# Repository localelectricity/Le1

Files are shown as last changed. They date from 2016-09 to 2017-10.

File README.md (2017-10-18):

# L.E.One
A universal input USB power supply which makes it easy to charge your cell phone or light your home, using any type of electrical energy source. 

The power supply is able to accept DC as well as AC electricity, which is then converted into a smooth, uniform 5V for USB powered devices.

The power supply also provides feedback on how your generation device is performing through a simple UI.

# System Overview

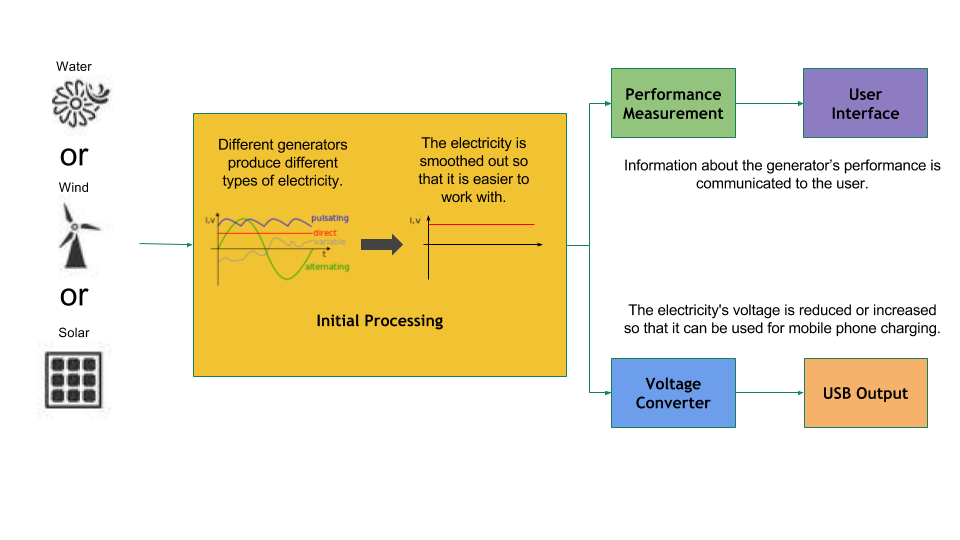
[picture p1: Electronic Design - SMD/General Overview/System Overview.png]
System Overview


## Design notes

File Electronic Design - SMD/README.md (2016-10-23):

# Electronic Design
All electronic design files are kept here.

Contents description:

- [Eagle Files & BOMs](Eagle%20Files%20&%20BOMs): Contains all the files required to view our designs in CadSoft Eagle as well as bills of materials.

- [Gerbers](Gerbers): Contains all the files required by PCB manufacturers.

- [General Overview](General%20Overview): Contains the overview image files.

- [PDFs](PDFs): Contains PDF versions of schematics and PCB layouts of our designs.

# Block Diagramme

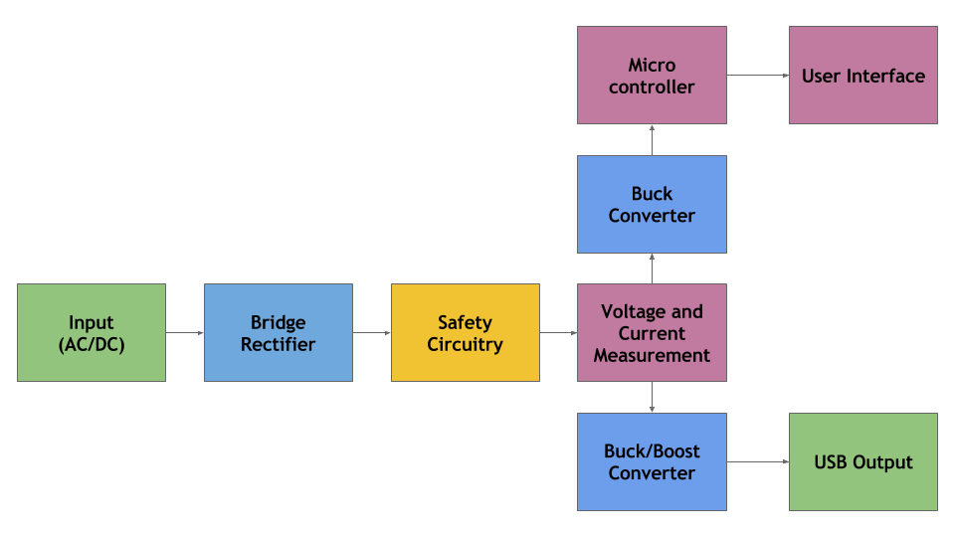
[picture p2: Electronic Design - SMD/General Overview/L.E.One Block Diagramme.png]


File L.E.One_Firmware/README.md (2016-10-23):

# MVP Firmware
All firmware for the L.E.One is kept here.

Firmware is written using arduino.

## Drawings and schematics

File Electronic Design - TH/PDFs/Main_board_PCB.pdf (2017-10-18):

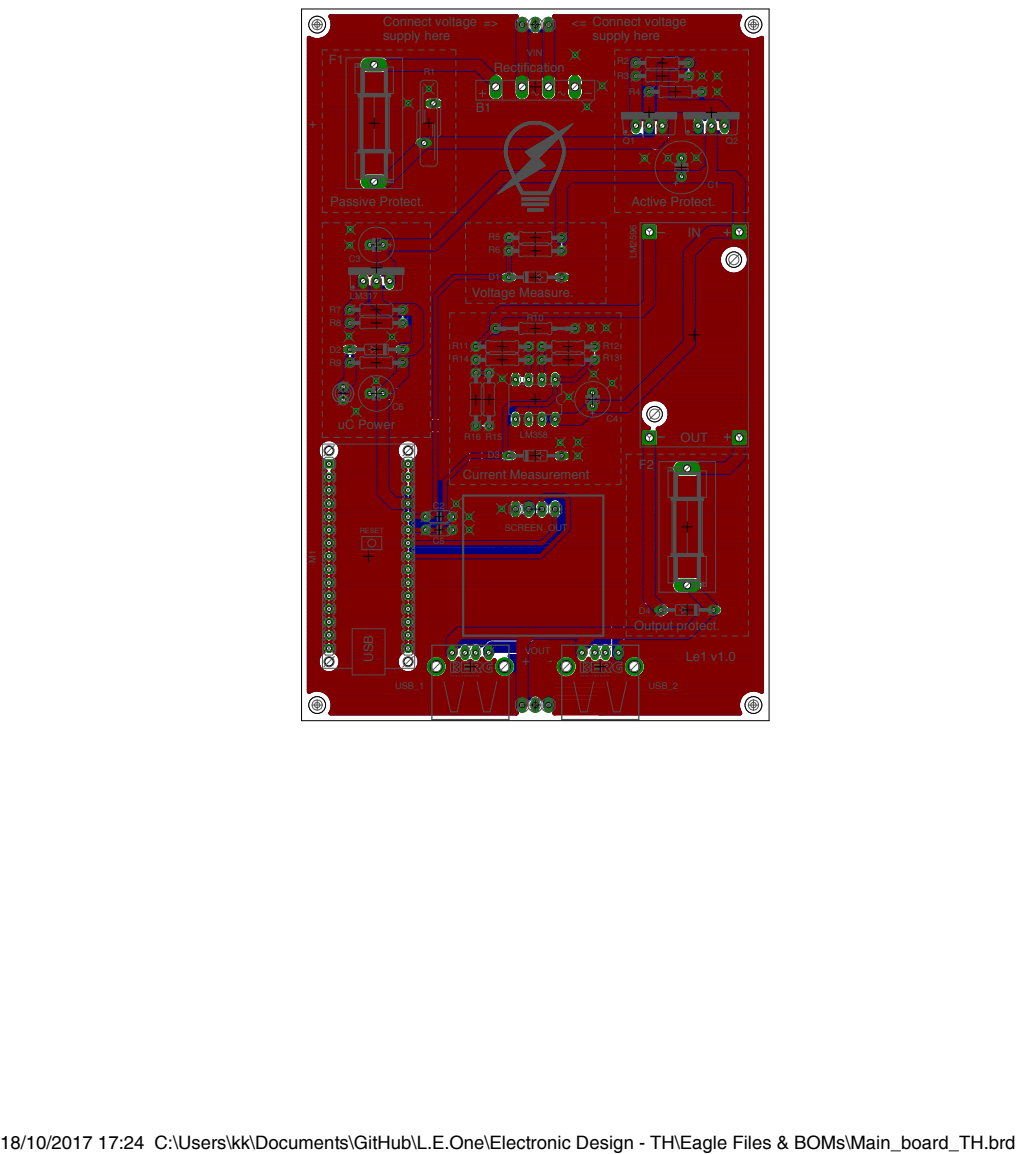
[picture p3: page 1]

+ Connect voltage | | R2

VIN

LM317 | Voltage Measure.

uC Power | C4

18/10/2017 17:24 C:\Users\kk\Documents\GitHub\L.E.One\Electronic Design - TH\Eagle Files & BOMs\Main_board_TH.brd

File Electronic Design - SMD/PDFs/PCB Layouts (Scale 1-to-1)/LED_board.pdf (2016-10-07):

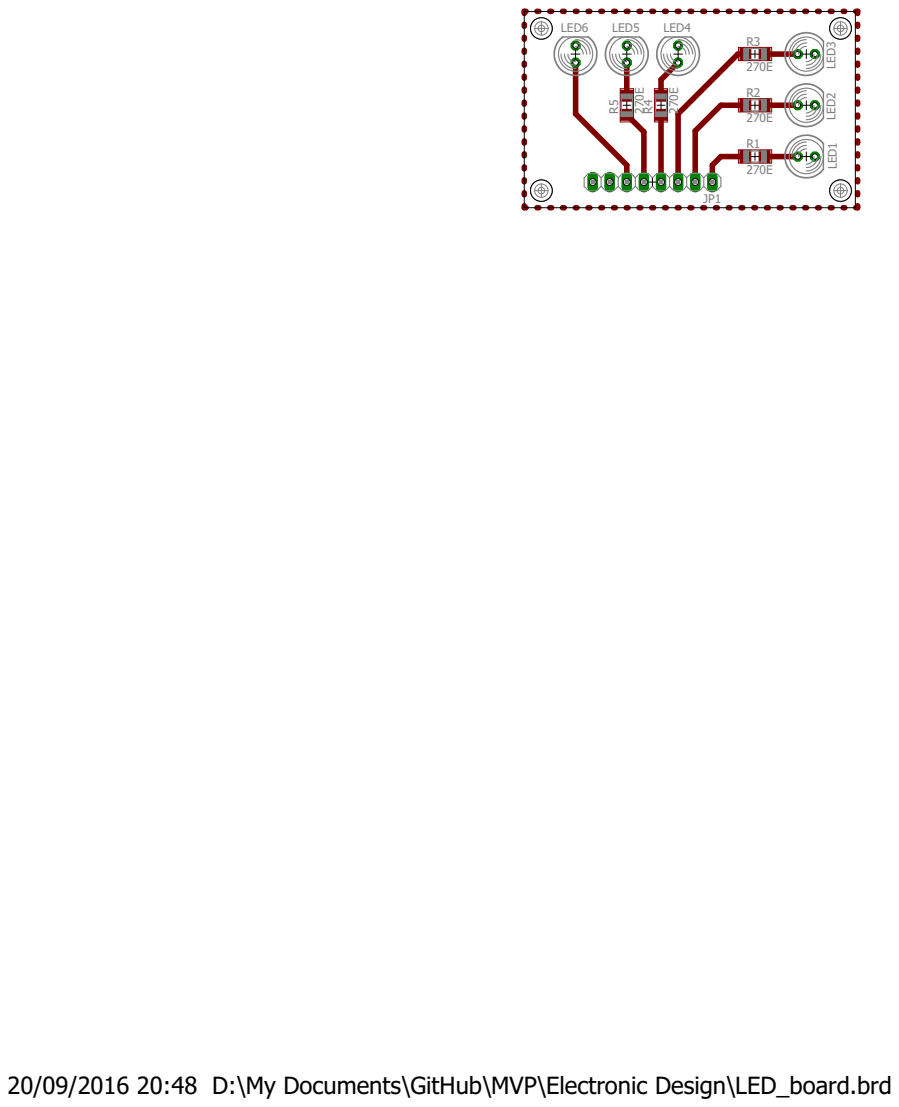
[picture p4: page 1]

20/09/2016 20:48 D:\My Documents\GitHub\MVP\Electronic Design\LED_board.brd

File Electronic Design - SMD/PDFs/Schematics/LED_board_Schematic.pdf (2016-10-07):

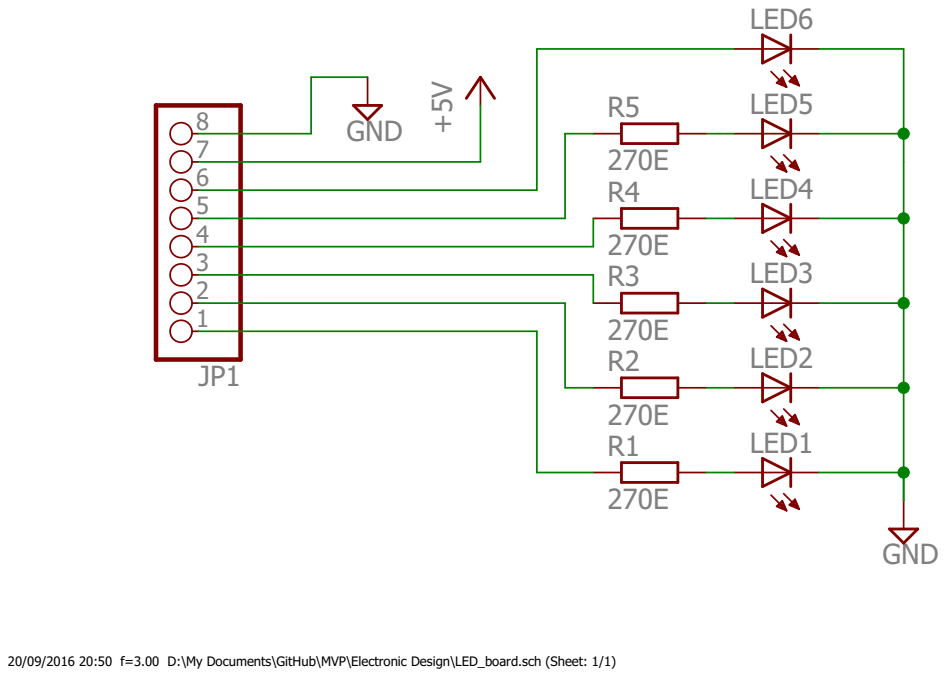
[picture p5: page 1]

20/09/2016 20:50 f=3.00 D:\My Documents\GitHub\MVP\Electronic Design\LED_board.sch (Sheet: 1/1)

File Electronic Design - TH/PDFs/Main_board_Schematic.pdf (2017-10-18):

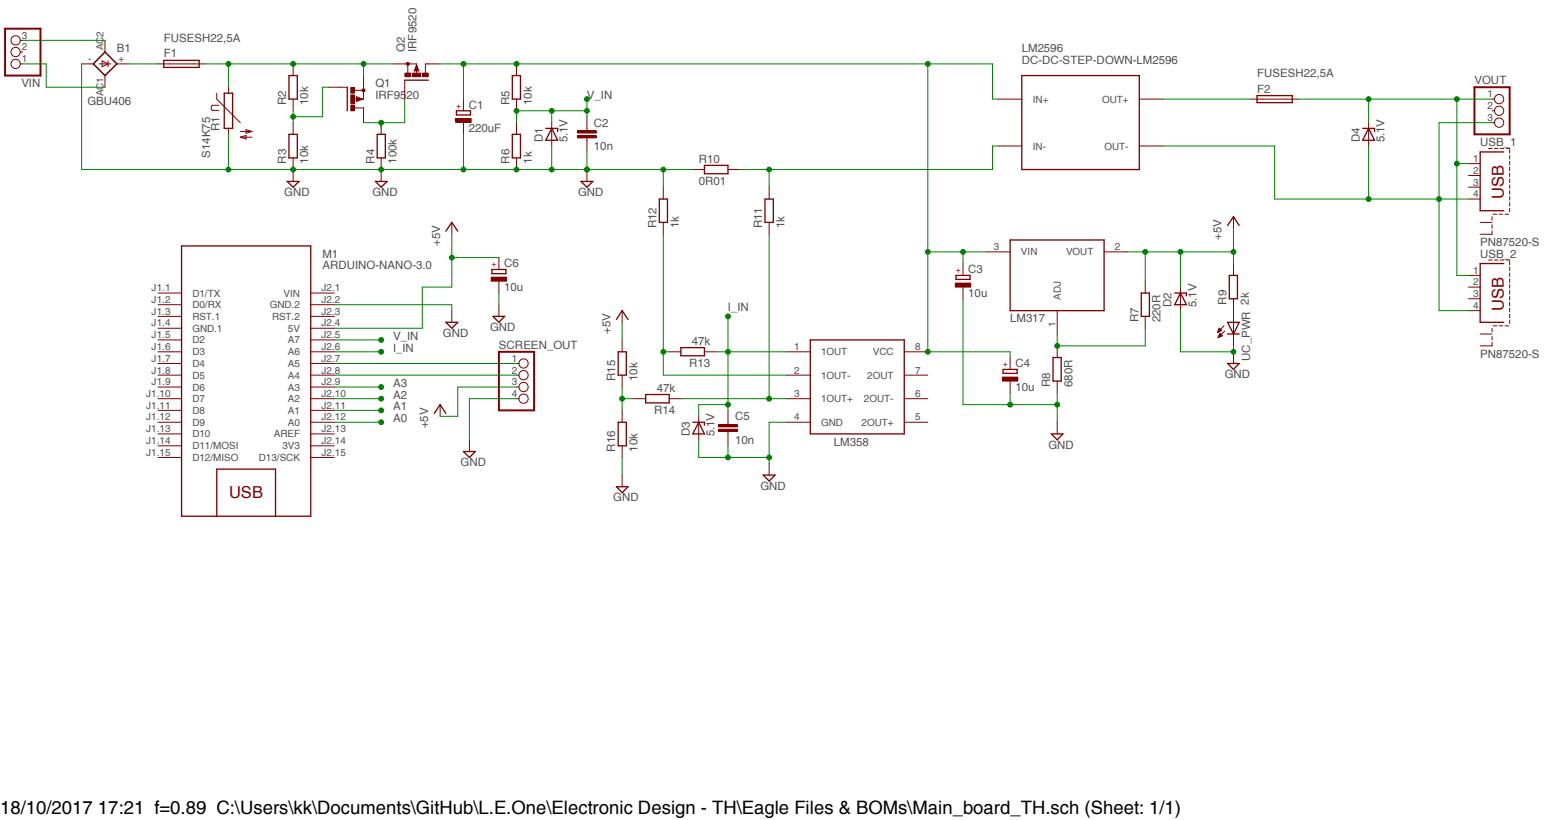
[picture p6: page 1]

DC-DC-STEP-DOWN-LM2596

18/10/2017 17:21 f=0.89 C:\Users\kk\Documents\GitHub\L.E.One\Electronic Design - TH\Eagle Files & BOMs\Main_board_TH.sch (Sheet: 1/1)

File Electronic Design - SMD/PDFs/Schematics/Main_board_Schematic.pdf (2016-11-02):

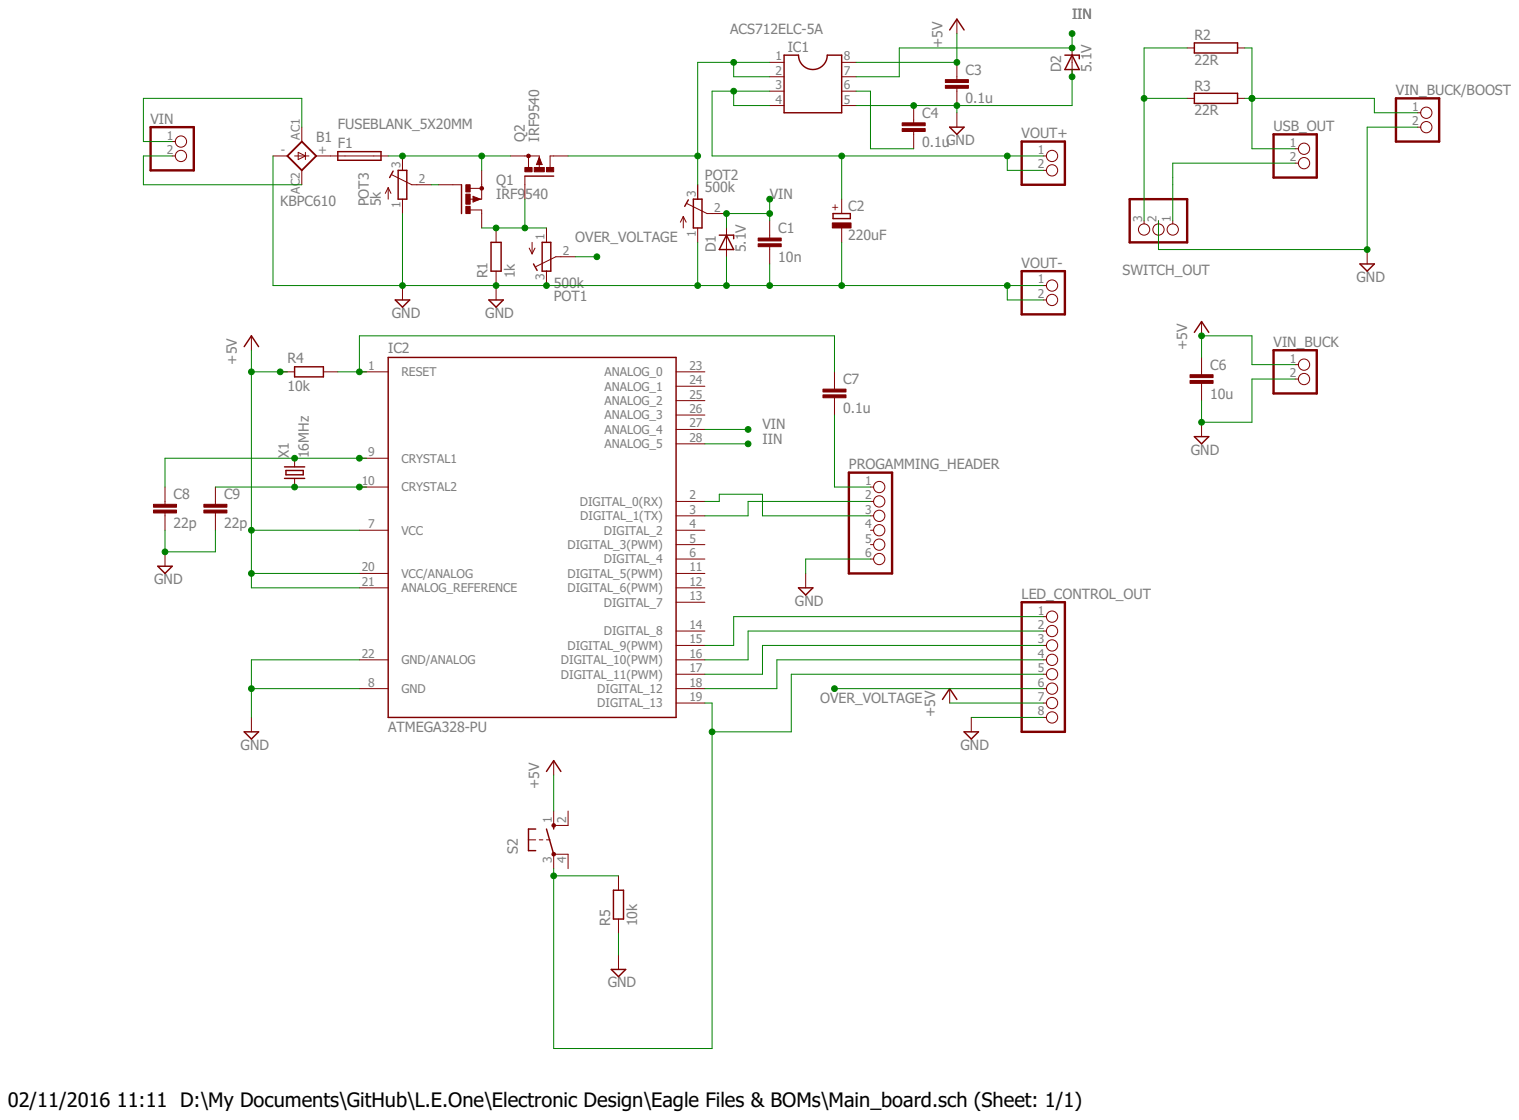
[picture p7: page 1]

02/11/2016 11:11 D:\My Documents\GitHub\L.E.One\Electronic Design\Eagle Files & BOMs\Main_board.sch (Sheet: 1/1)

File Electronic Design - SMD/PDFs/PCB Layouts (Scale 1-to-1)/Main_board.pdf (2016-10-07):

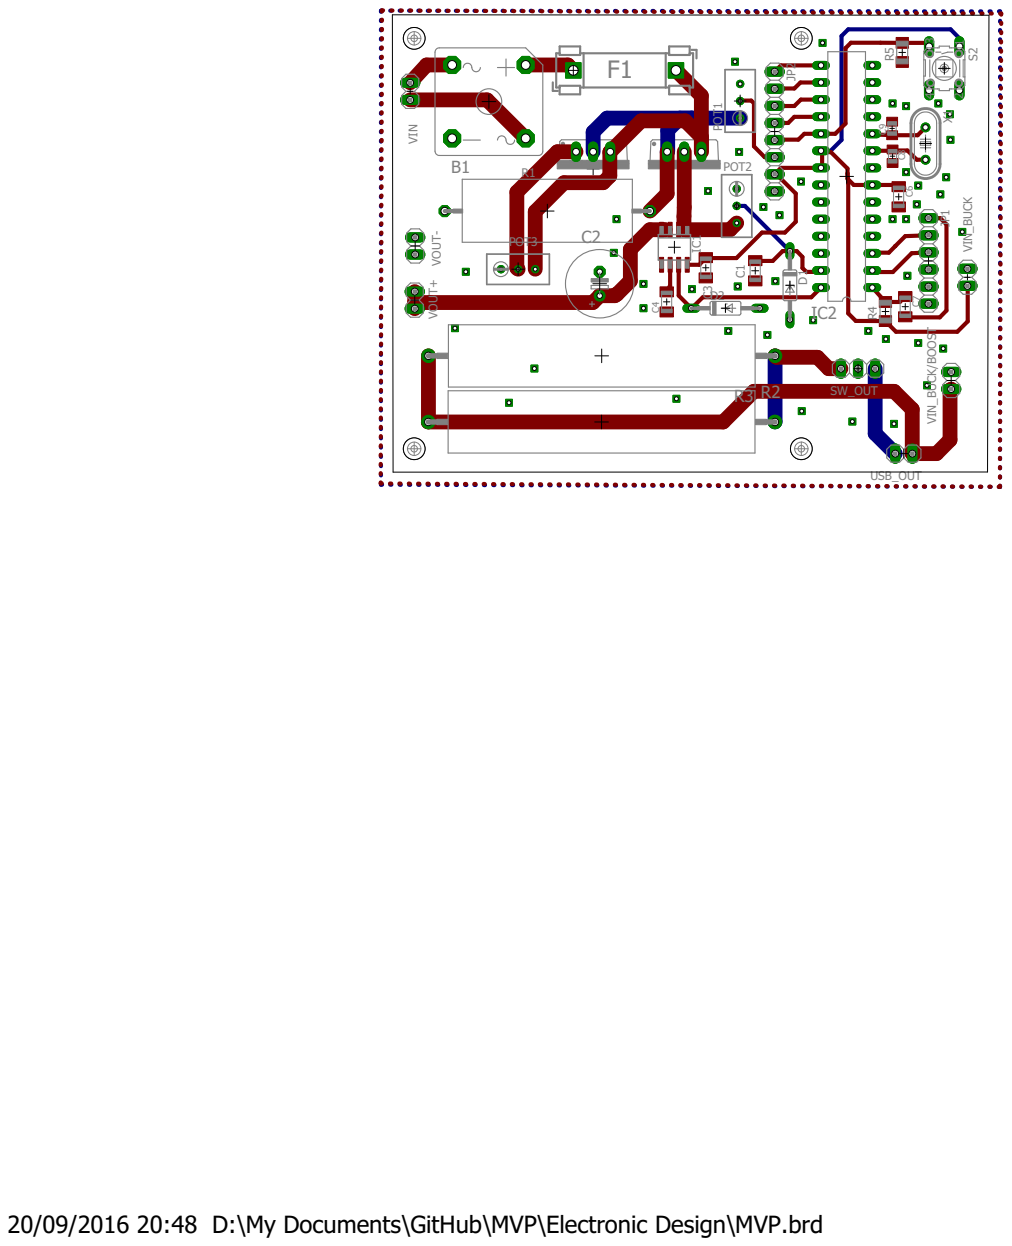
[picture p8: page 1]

20/09/2016 20:48 D:\My Documents\GitHub\MVP\Electronic Design\MVP.brd

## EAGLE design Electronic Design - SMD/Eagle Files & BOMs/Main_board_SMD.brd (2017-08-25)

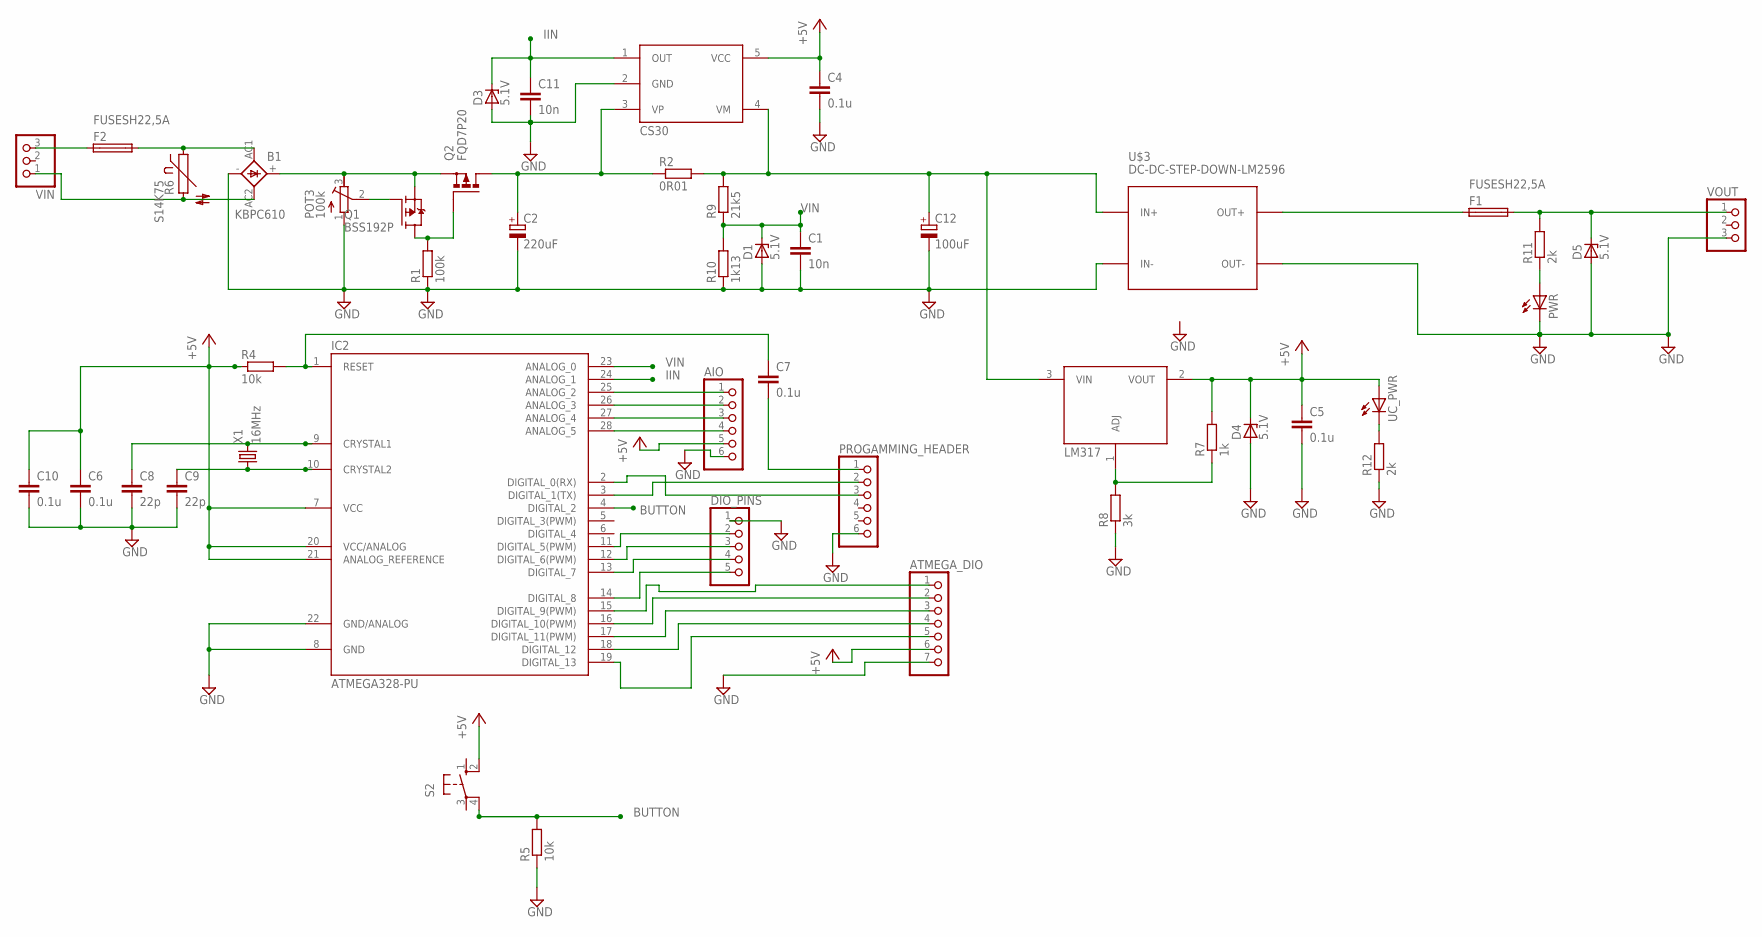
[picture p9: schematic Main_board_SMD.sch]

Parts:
AIO: PINHD-1X6; 1X06
ATMEGA_DIO: PINHD-1X7; 1X07
B1: KBPC610; GBPC6
C1, C11: 10n; C1206K
C2: 220uF; E3,5-10
C4, C5, C6, C7, C10: 0.1u; C1206K
C8, C9: 22p; C0805K
C12: 100uF; E3,5-8
D1, D3, D4, D5: 5.1V; DO35Z10
DIO_PINS: PINHD-1X5; 1X05
F1, F2: FUSESH22,5A; SH22,5A
IC2: ATMEGA328-PU; DIL28-3
POT3: 100k; RTRIM3296W
PROGAMMING_HEADER: PINHD-1X6; 1X06
PWR: LEDSMT1206; 1206
Q1: BSS192P
Q2: FQD7P20; TO252
R1: 100k; 0207/10
R2: 0R01; M1206
R4, R5: 10k; R1206
R6: S14K75; S14K17
R7: 1k; R1206
R8: 3k; R1206
R9: 21k5; R0805
R10: 1k13; R0805
R11, R12: 2k; R1206
S2: 10-XX; B3F-10XX
U$1: LM317; TO220BH
U$2: CS30; SOT23-5L
U$3: DC-DC-STEP-DOWN-LM2596
UC_PWR: LEDSMT1206; 1206
VIN: PINHD-1X3; 1X03
VOUT: PINHD-1X3; 1X03
X1: 16MHz; HC49/S

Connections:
+5V: AIO.5, ATMEGA_DIO.6, C4.1, C5.1, C6.1, C10.1, D4.C, IC2.7 (VCC), IC2.20 (VCC/ANALOG), IC2.21 (ANALOG_REFERENCE), R4.1, R7.2, S2.2 (S1), U$1.2 (VOUT), U$2.5 (VCC), UC_PWR.A
ANALOG_2: AIO.1, IC2.25 (ANALOG_2)
ANALOG_3: AIO.2, IC2.26 (ANALOG_3)
ANALOG_4: AIO.3, IC2.27 (ANALOG_4)
ANALOG_5: AIO.4, IC2.28 (ANALOG_5)
BUTTON: IC2.4 (DIGITAL_2), R5.2, S2.4 (P1)
CRYSTAL1: C8.1, IC2.9 (CRYSTAL1), X1.2
CRYSTAL2: C9.1, IC2.10 (CRYSTAL2), X1.1
D5: DIO_PINS.2, IC2.11 (DIGITAL_5(PWM))
D6: DIO_PINS.3, IC2.12 (DIGITAL_6(PWM))
D7: DIO_PINS.4, IC2.13 (DIGITAL_7)
D8: DIO_PINS.5, IC2.14 (DIGITAL_8)
D9: ATMEGA_DIO.1, IC2.15 (DIGITAL_9(PWM))
D10: ATMEGA_DIO.2, IC2.16 (DIGITAL_10(PWM))
D11: ATMEGA_DIO.3, IC2.17 (DIGITAL_11(PWM))
D12: ATMEGA_DIO.4, IC2.18 (DIGITAL_12)
D13: ATMEGA_DIO.5, IC2.19 (DIGITAL_13)
GND: AIO.6, ATMEGA_DIO.7, B1.-, C1.2, C2.-, C4.2, C5.2, C6.2, C8.2, C9.2, C10.2, C11.2, C12.-, D1.A, D3.A, D4.A, D5.A, DIO_PINS.1, IC2.8 (GND), IC2.22 (GND/ANALOG), POT3.1 (A), PROGAMMING_HEADER.6, PWR.C, R1.1, R5.1, R8.1, R10.1, R12.1, U$2.2 (GND), U$3.IN-, U$3.OUT-, VOUT.3
IIN: C11.1, D3.C, IC2.24 (ANALOG_1), U$2.1 (OUT)
unnamed: F2.1, VIN.3
unnamed: IC2.3 (DIGITAL_1(TX)), PROGAMMING_HEADER.2
unnamed: IC2.2 (DIGITAL_0(RX)), PROGAMMING_HEADER.3
unnamed: C7.2, PROGAMMING_HEADER.1
unnamed: PWR.A, R11.1
unnamed: R7.1, R8.2, U$1.1 (ADJ)
unnamed: R12.2, UC_PWR.C
Q1_GATE: POT3.2 (S), Q1.1 (G)
Q2_GATE: Q1.2 (D), Q1.4 (D), Q2.1 (G), R1.2
RESET: C7.1, IC2.1 (RESET), R4.2
VIN: C1.1, D1.C, IC2.23 (ANALOG_0), R9.1, R10.2
VIN_AC1: B1.AC1, F2.2, R6.1
VIN_AC2: B1.AC2, R6.2, VIN.1
VIN_CURRENT_MEASURED: C12.+, R2.2, R9.2, U$1.3 (VIN), U$2.4 (VM), U$3.IN+
VIN_PROTECTED: C2.+, Q2.3 (D), R2.1, U$2.3 (VP)
VIN_UNPROTECTED: B1.+, POT3.3 (E), Q1.3 (S), Q2.2 (S)
VOUT_FINAL: D5.C, F1.2, R11.2, VOUT.1
VOUT_PREFUSE: F1.1, U$3.OUT+

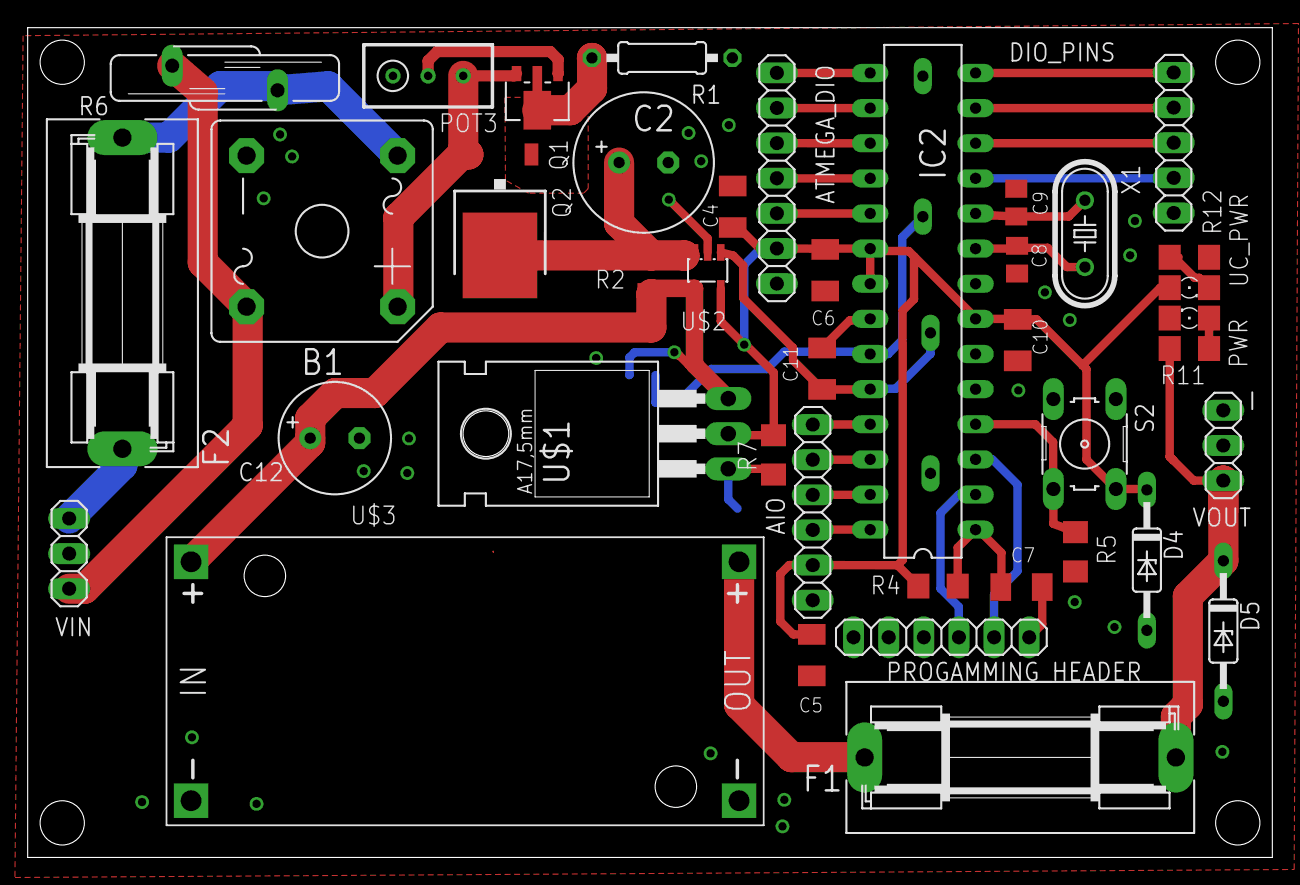
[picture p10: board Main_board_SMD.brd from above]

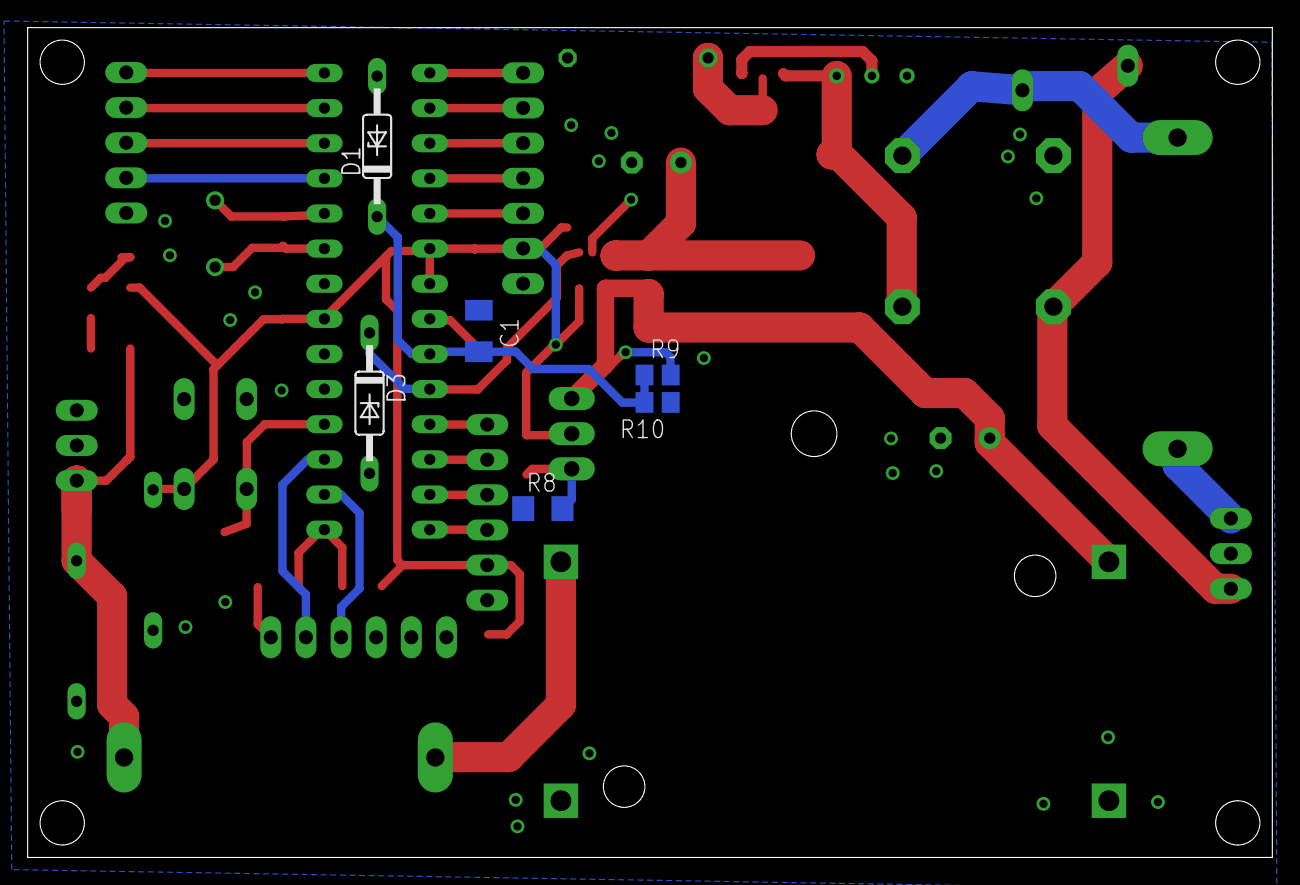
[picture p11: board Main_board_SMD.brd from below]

Board: 2 copper layers, 90.0 x 60.0 mm, 46 parts (6 on the bottom side), 37 nets.

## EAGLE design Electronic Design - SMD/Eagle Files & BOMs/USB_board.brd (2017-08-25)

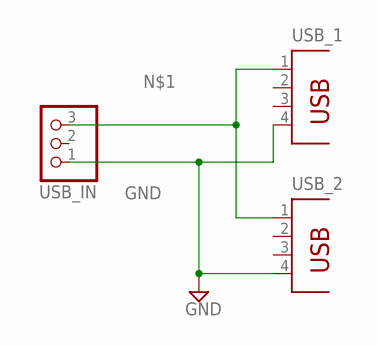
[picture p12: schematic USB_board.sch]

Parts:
USB_1, USB_2: PN87520
USB_IN: PINHD-1X3; 1X03

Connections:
GND: USB_1.4, USB_2.4, USB_IN.1
unnamed: USB_1.1, USB_2.1, USB_IN.3

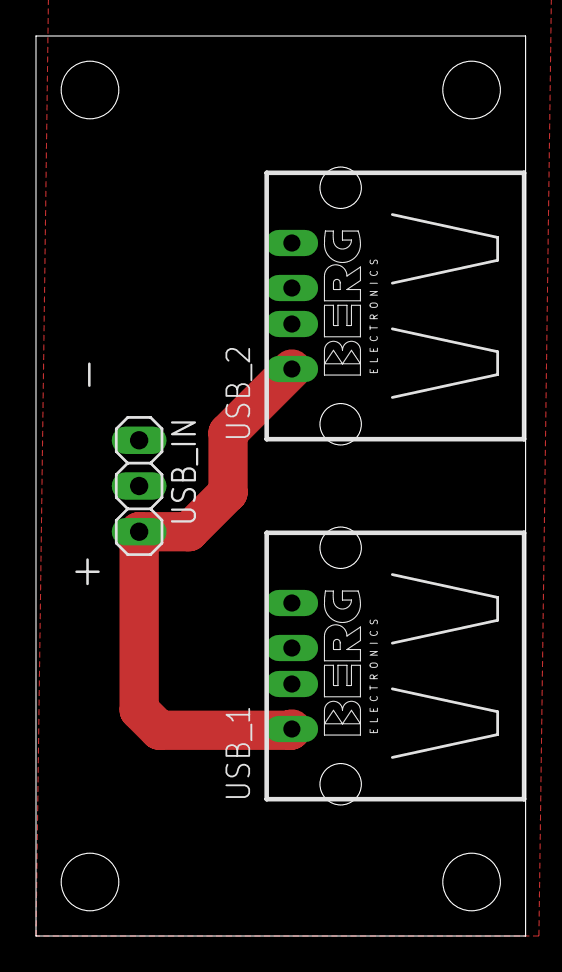
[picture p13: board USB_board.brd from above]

Board: 2 copper layers, 27.2 x 50.0 mm, 3 parts (0 on the bottom side), 2 nets.

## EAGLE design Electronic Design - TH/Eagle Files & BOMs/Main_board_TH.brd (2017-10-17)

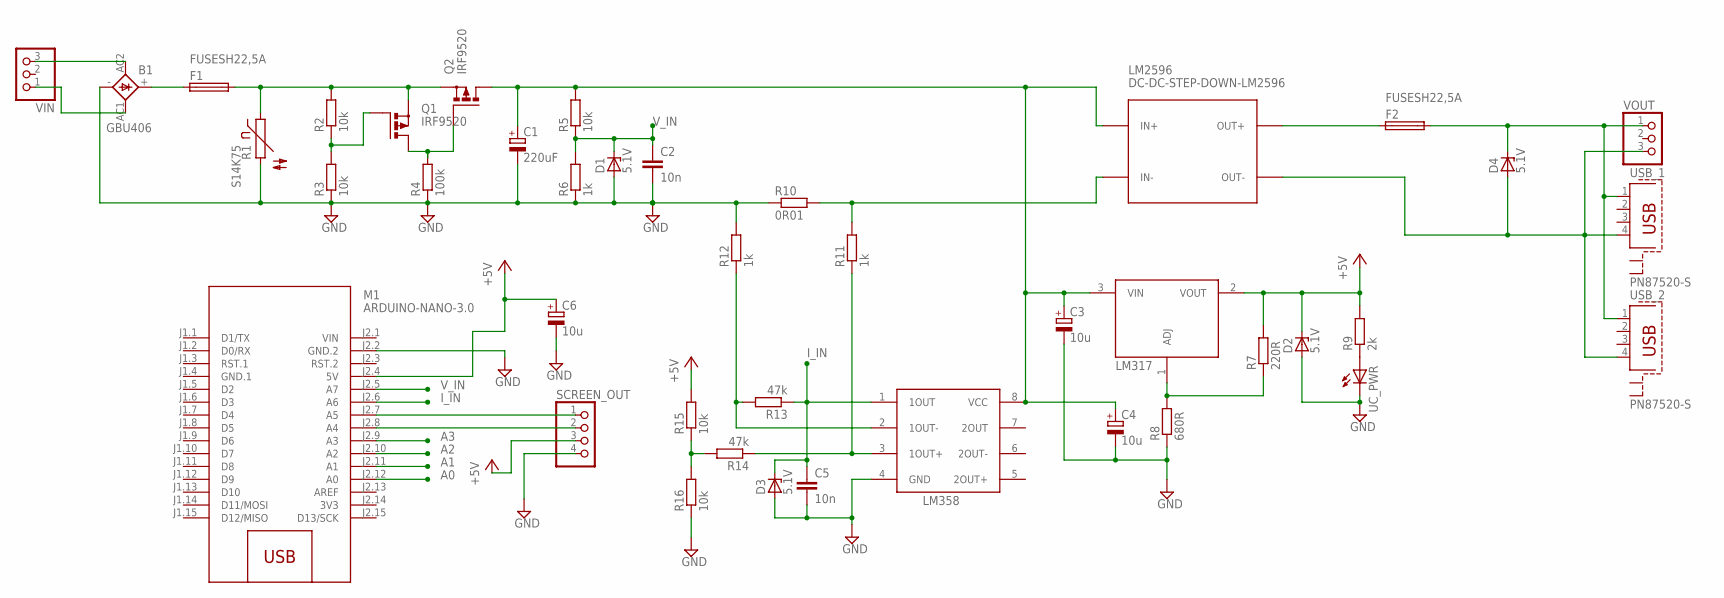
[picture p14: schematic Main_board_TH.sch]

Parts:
B1: GBU406; GBU4S
C1: 220uF; E3,5-10
C2, C5: 10n; C050-024X044
C3, C4, C6: 10u; E2,5-7
D1, D2, D3, D4: 5.1V; DO35Z10
F1, F2: FUSESH22,5A; SH22,5A
LM317: LM317; TO220BV
LM358: LM358; DIL08
LM2596: DC-DC-STEP-DOWN-LM2596
M1: ARDUINO-NANO-3.0
Q1, Q2: IRF9520; TO220BV
R1: S14K75; S14K17
R2, R3, R5, R15, R16: 10k; 0207/10
R4: 100k; 0207/10
R6, R11, R12: 1k; 0207/10
R7: 220R; 0207/10
R8: 680R; 0207/10
R9: 2k; 0207/10
R10: 0R01; 0207/15
R13, R14: 47k; 0207/10
SCREEN_OUT: PINHD-1X4; 1X04
UC_PWR: LED3MM
USB_1, USB_2: PN87520-S
VIN: PINHD-1X3; 1X03
VOUT: PINHD-1X3; 1X03

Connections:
3V3: M1.J2.14 (3V3)
+5V: C6.+, D2.C, LM317.2 (VOUT), M1.J2.4 (5V), R7.2, R9.2, R15.2, SCREEN_OUT.3
A0: M1.J2.12 (A0)
A1: M1.J2.11 (A1)
A2: M1.J2.10 (A2)
A3: M1.J2.9 (A3)
A4: M1.J2.8 (A4), SCREEN_OUT.2
A5: M1.J2.7 (A5), SCREEN_OUT.1
GND: B1.-, C1.-, C2.2, C3.-, C4.-, C5.2, C6.-, D1.A, D2.A, D3.A, LM358.4 (GND), M1.J2.2 (GND.2), R1.2, R3.1, R4.1, R6.1, R8.1, R10.1, R12.2, R16.1, SCREEN_OUT.4, UC_PWR.K (C)
GND.1: M1.J1.4 (GND.1)
I_IN: C5.1, D3.C, LM358.1 (1OUT), M1.J2.6 (A6), R13.1
unnamed: B1.+, F1.1
unnamed: R9.1, UC_PWR.A
unnamed: Q1.1 (G), R2.1, R3.2
unnamed: LM2596.IN-, R10.2, R11.2
unnamed: LM358.3 (1OUT+), R11.1, R14.1
unnamed: LM358.2 (1OUT-), R12.1, R13.2
unnamed: B1.AC1 (AC2), VIN.1
unnamed: R14.2, R15.1, R16.2
unnamed: B1.AC2 (AC1), VIN.3
unnamed: D4.A, LM2596.OUT-, USB_1.4, USB_2.4, VOUT.3
unnamed: LM317.1 (ADJ), R7.1, R8.2
Q2_GATE: Q1.2 (D), Q2.1 (G), R4.2
VIN: M1.J2.1 (VIN)
VIN_PROTECTED: C1.+, C3.+, C4.+, LM317.3 (VIN), LM358.8 (VCC), LM2596.IN+, Q2.2 (D), R5.2
VIN_UNPROTECTED: F1.2, Q1.3 (S), Q2.3 (S), R1.1, R2.2
VOUT_FINAL: D4.C, F2.2, USB_1.1, USB_2.1, VOUT.1
VOUT_PREFUSE: F2.1, LM2596.OUT+
V_IN: C2.1, D1.C, M1.J2.5 (A7), R5.1, R6.2

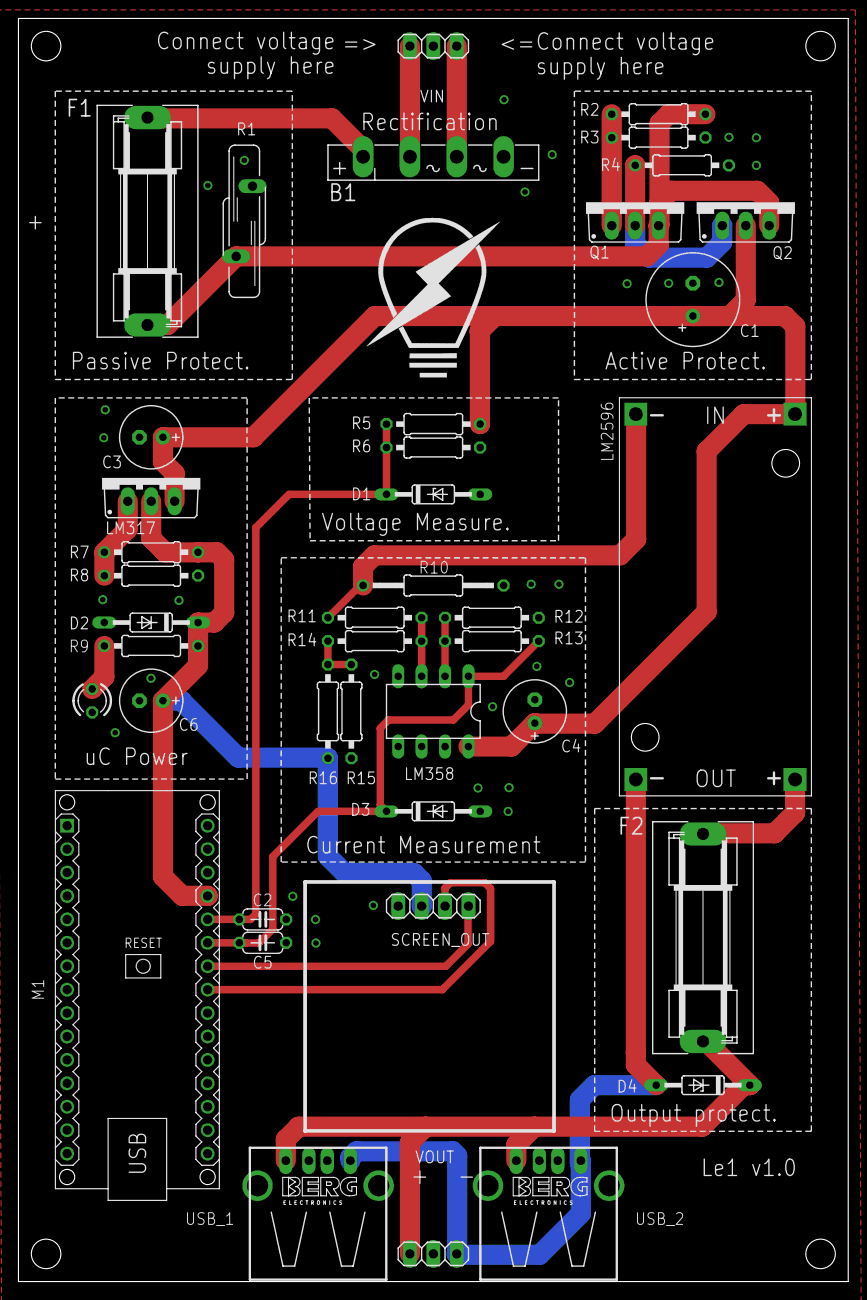
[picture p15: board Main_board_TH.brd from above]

Board: 2 copper layers, 90.0 x 137.0 mm, 41 parts (0 on the bottom side), 22 nets.

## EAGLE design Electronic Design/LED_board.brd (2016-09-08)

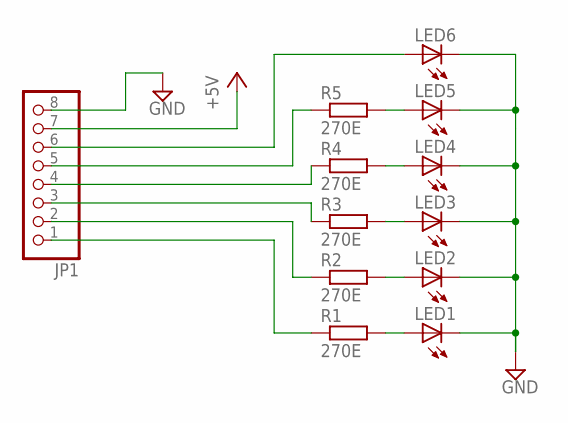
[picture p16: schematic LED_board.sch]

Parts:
JP1: PINHD-1X8; 1X08
LED1, LED2, LED3, LED4, LED5, LED6: LED5MM
R1, R2, R3, R4, R5: 270E; R0805

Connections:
+5V: JP1.7
GND: JP1.8, LED1.K (C), LED2.K (C), LED3.K (C), LED4.K (C), LED5.K (C), LED6.K (C)
unnamed: JP1.1, R1.1
unnamed: JP1.2, R2.1
unnamed: JP1.3, R3.1
unnamed: JP1.4, R4.1
unnamed: JP1.6, LED6.A
unnamed: JP1.5, R5.1
unnamed: LED5.A, R5.2
unnamed: LED4.A, R4.2
unnamed: LED3.A, R3.2
unnamed: LED2.A, R2.2
unnamed: LED1.A, R1.2

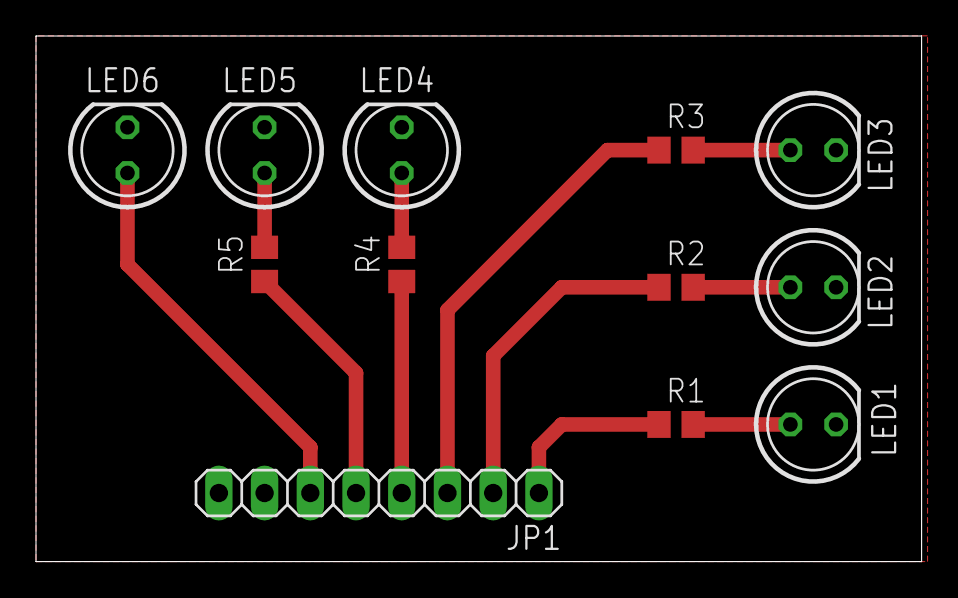
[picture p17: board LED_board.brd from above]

Board: 2 copper layers, 49.2 x 29.2 mm, 12 parts (0 on the bottom side), 12 nets.

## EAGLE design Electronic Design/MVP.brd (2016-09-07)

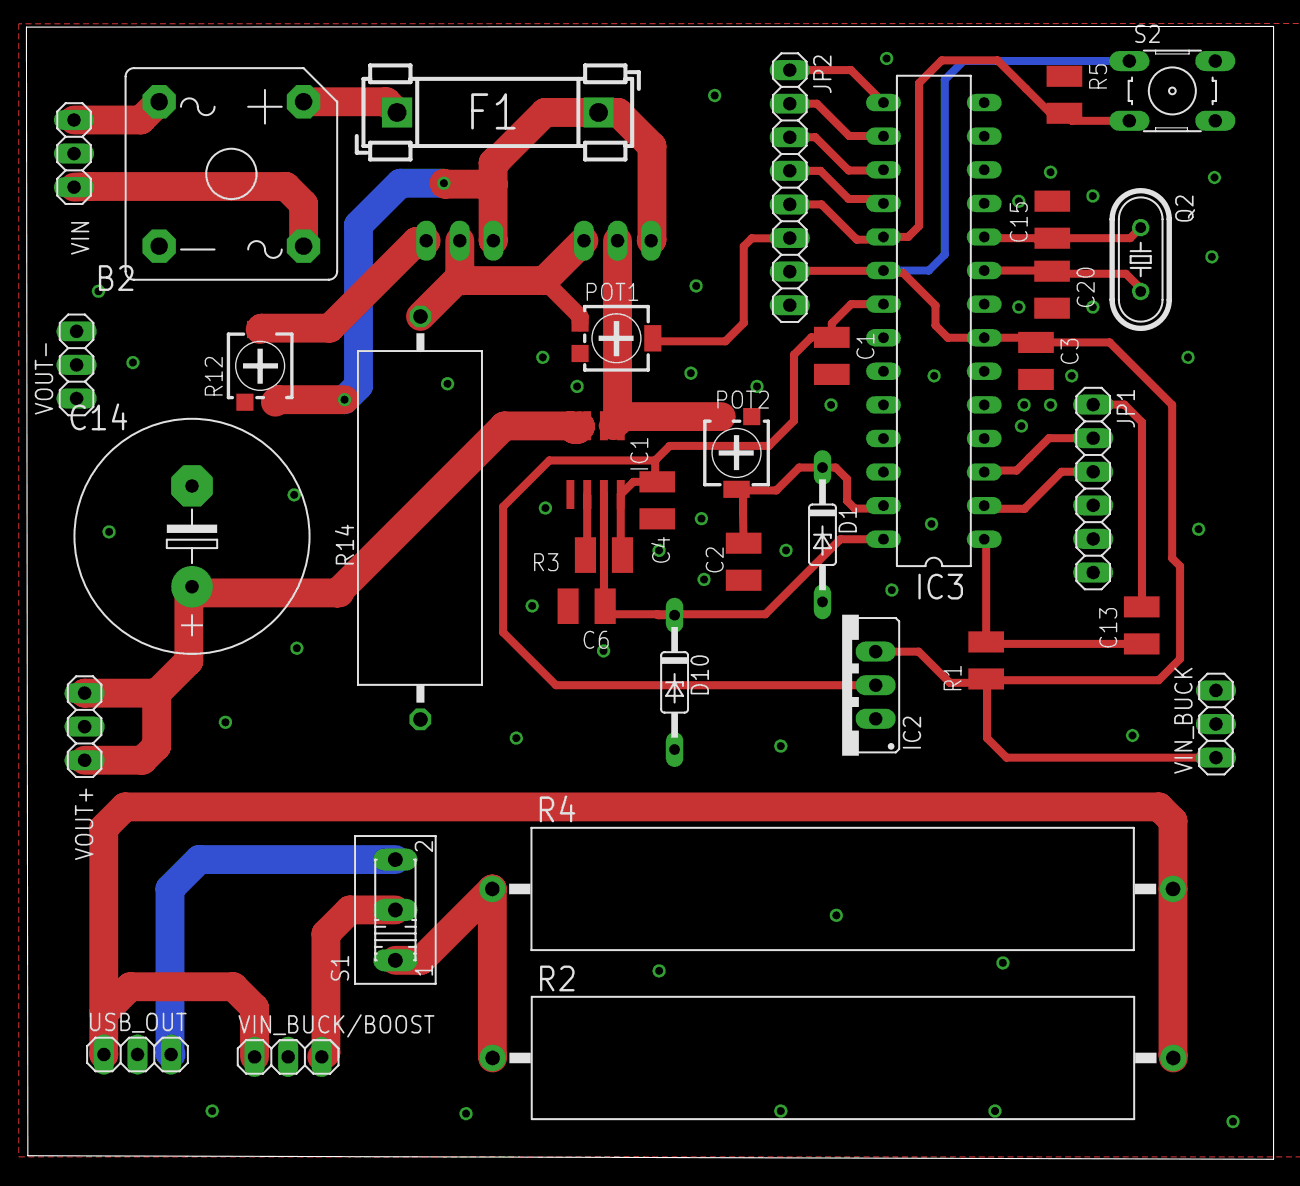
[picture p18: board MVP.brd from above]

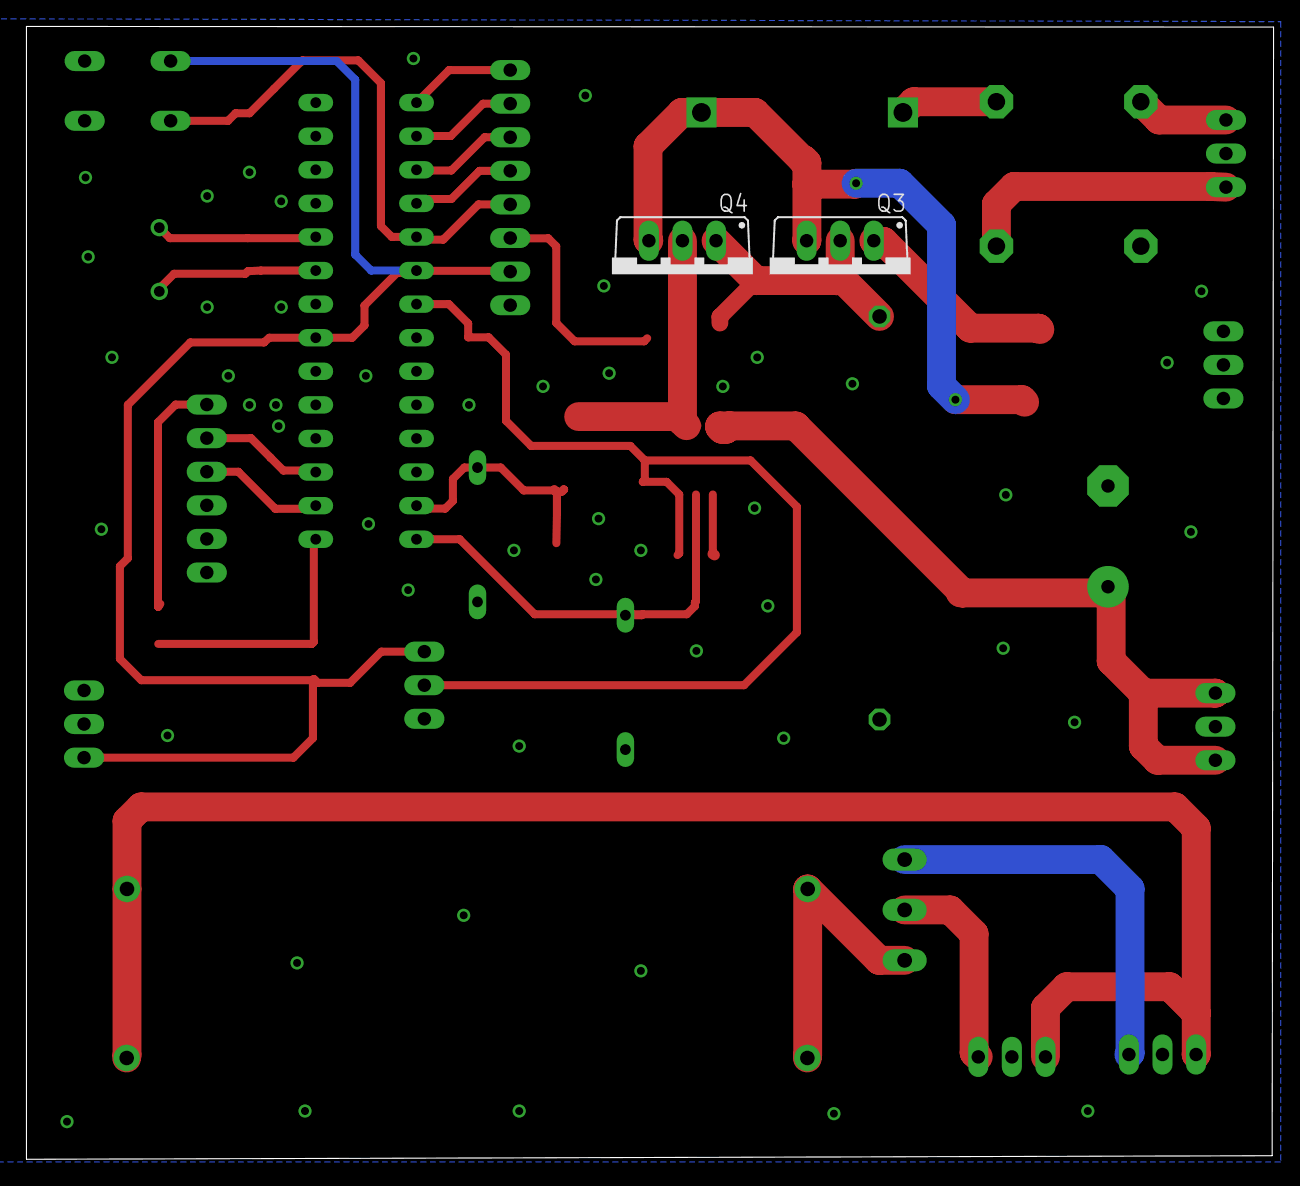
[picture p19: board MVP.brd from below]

Board: 2 copper layers, 94.3 x 85.7 mm, 38 parts (2 on the bottom side), 30 nets.

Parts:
B2: GBPC3506W; GBPC6
C1, C3, C6: 10u; C1210
C2: 10n; C1210
C4: 0.1u; C1210
C13: 100n; C1210
C14: ECA2DHG221; E7,5-18
C15, C20: 22n; C1210
D1, D10: 5.1V; DO35Z10
F1: FUSEBLANK_5X20MM; FUSE_HOLDER_5X20MM
IC1: ACS711KLCTR-12AB-T; SOIC8
IC2: TO220S
IC3: ATMEGA328-PU; DIL28-3
JP1: 1X06
JP2: 1X08
POT1, POT2: 470k; RTRIM4G/J
Q2: 16MHz; HC49/S
Q3, Q4: IRF9540; TO220BV
R1, R5: 10k; R1210
R2, R4: 22R; RWM8X45
R3: 100k; R1210
R12: 4.7k; RTRIM4G/J
R14: 1k; VTA52
S1: 255SB
S2: B3F-10XX
USB_OUT: 1X03
VIN: 1X03
VIN_BUCK: 1X03
VIN_BUCK/BOOST: 1X03
VOUT+: 1X03
VOUT-: 1X03

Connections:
+3V3: C1.1, C4.1, IC1.8, IC2.2, IC3.21, R3.1
+5V: C3.1, IC2.3, IC3.7, IC3.20, JP2.7, R1.1, S2.1, VIN_BUCK.1
GND: B2.-, C1.2, C2.2, C3.2, C4.2, C6.2, C14.-, C15.2, C20.2, D1.A, D10.A, IC1.5, IC2.1, IC3.8, IC3.22, JP1.6, JP2.8, POT1.3, POT2.1, R5.1, R12.1, R14.1, VIN_BUCK.3, VOUT-.1, VOUT-.3
IIN: C6.1, D10.C, IC1.7, IC3.28
M1S: C14.+, IC1.3, IC1.4, VOUT+.1, VOUT+.3
unnamed: B2.+, F1.1
unnamed: IC1.6, R3.2
unnamed: IC1.1, IC1.2, POT2.3, Q4.D
unnamed: IC3.3, JP1.2
unnamed: IC3.2, JP1.3
unnamed: IC3.15, JP2.1
unnamed: IC3.19, JP2.5, R5.2, S2.3
unnamed: IC3.16, JP2.2
unnamed: F1.2, Q3.S, Q4.S, R12.3
unnamed: IC3.17, JP2.3
unnamed: IC3.18, JP2.4
unnamed: C13.2, JP1.1
unnamed: C15.1, IC3.10, Q2.1
unnamed: C20.1, IC3.9, Q2.2
unnamed: C13.1, IC3.1, R1.2
unnamed: B2.AC2, VIN.3
unnamed: B2.AC1, VIN.1
unnamed: S1.2, VIN_BUCK/BOOST.3
unnamed: R2.2, R4.2, USB_OUT.1, VIN_BUCK/BOOST.1
unnamed: R2.1, R4.1, S1.1
unnamed: S1.3, USB_OUT.3
unnamed: POT1.1, Q3.D, Q4.G, R14.2
unnamed: Q3.G, R12.2
OVERV: JP2.6, POT1.2
VIN: C2.1, D1.C, IC3.27, POT2.2

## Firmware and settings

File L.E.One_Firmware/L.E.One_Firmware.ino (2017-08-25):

// firmware for the MVP

#include <SPI.h>
#include <Wire.h>
#include <Adafruit_GFX.h>
#include <Adafruit_SSD1306.h>

#define OLED_RESET 4
Adafruit_SSD1306 display(OLED_RESET);

#define SSD1306_LCDHEIGHT 64
#if (SSD1306_LCDHEIGHT != 64)
#error("Height incorrect, please fix Adafruit_SSD1306.h!");
#endif

  const int voltagePin = 0;
  const int currentPin = 1;
  float Vin=0;                     // input voltage
  float Iin=0;                     // input current
  float Iin_raw=0;                 // untuned current input
  float Pin=0;                     // input power in
  
  const int numReadings = 30;      // number of reading taken for smoothing
  int rstButton = 0;               // reset button 
  int pinval=0;                    // pin value

  int Vreadings[numReadings];      // the readings from the analog input
  int VreadIndex = 0;              // the index of the current reading
  int Vtotal = 0;                  // the running total
  int Vaverage = 0;                // the average

  
  int Ireadings[numReadings];      // the readings from the analog input
  int IreadIndex = 0;              // the index of the current reading
  int Itotal = 0;                  // the running total
  int Iaverage = 0;                // the average
  int Ioffset = 0;               // initial current offset for ACS712ELC-5A
  int IinOld = 0;                  // current value from previous iteration (used for calibration)
  
  int Preadings[numReadings];      // the readings from the analog input
  int PreadIndex = 0;              // the index of the current reading
  int Ptotal = 0;                  // the running total

  float x1, y1, x2, y2, x3, y3, x4, y4, x5, y5;
  int mainGaugesize = 18;
  int mainHandsize = mainGaugesize-5;
  int mainTicksize = 3;
  int otherGaugesize = 14;
  int otherHandsize = otherGaugesize-5;
  int otherTicksize = 3;
  
  int VgaugeCenterX = 20;
  int VgaugeCenterY = 25;
  int IgaugeCenterX = 108;
  int IgaugeCenterY = 25;
  int PgaugeCenterX = 64;
  int PgaugeCenterY = 20;

void setup() {
  // initialize digital pins as outputs.
  pinMode(9, OUTPUT);
  pinMode(10, OUTPUT);
  pinMode(11, OUTPUT);
  pinMode(12, OUTPUT);
  pinMode(13, INPUT);
  
  Serial.begin(9600); // begin reading serial

    // by default, we'll generate the high voltage from the 3.3v line internally! (neat!)
  display.begin(SSD1306_SWITCHCAPVCC);
  // init done
  
  // Show image buffer on the display hardware.
  // Since the buffer is intialized with an Adafruit splashscreen
  // internally, this will display the splashscreen.
  display.setTextSize(0);
  display.setTextColor(WHITE);
  display.display();
  delay(2000);
  display.clearDisplay();  

 // below is the initialisation of the values used for the smoothing of voltage and current readings
 
    // initialize all the readings to 0:
  for (int thisReading = 0; thisReading < numReadings; thisReading++) {
    Vreadings[thisReading] = 0;
    }
  for (int thisReading = 0; thisReading < numReadings; thisReading++) {
    Ireadings[thisReading] = 0;
    }
    for (int thisReading = 0; thisReading < numReadings; thisReading++) {
    Preadings[thisReading] = 0;
    }
}

void loop() {

//// calbration button, allowing the calbration of the current sensor
//  rstButton = digitalRead (13);
//  if (rstButton == HIGH){
//    if ( Iin < 0.53 || Iin > 0.55){
//       if (Iin < 0.53){
//         Ioffset = Ioffset-1;
//         Serial.print("BOON");
//       }
//       else{
//        Ioffset = Ioffset+1;
//       }
//    digitalWrite(12, HIGH); // turn on LED to let user know the calbration is in progress
//    }
//    else{
//    Ioffset = Ioffset;
//    digitalWrite(12, LOW);
//    }
//  }
//  else{
//    Ioffset = Ioffset; 
//  }
//  IinOld = Iin;

// voltage reading smoothing

   // subtract the last reading:
  Vtotal = Vtotal - Vreadings[VreadIndex];
  // read from the sensor:
  Vreadings[VreadIndex] = analogRead(voltagePin);
  // add the reading to the total:
  Vtotal = Vtotal + Vreadings[VreadIndex];
  // advance to the next position in the array:
  VreadIndex = VreadIndex + 1;
  // if we're at the end of the array...
  if (VreadIndex >= numReadings) {
    // ...wrap around to the beginning:
    VreadIndex = 0;
  }
  // calculate the average:
  Vaverage = Vtotal / numReadings;
  delay(1);        // delay in between reads for stability

// current reading smoothing

   // subtract the last reading:
  Itotal = Itotal - Ireadings[IreadIndex];
  // read from the sensor:
  Ireadings[IreadIndex] = analogRead(currentPin);
  // add the reading to the total:
  Itotal = Itotal + Ireadings[IreadIndex];
  // advance to the next position in the array:
  IreadIndex = IreadIndex + 1;
  // if we're at the end of the array...
  if (IreadIndex >= numReadings) {
    // ...wrap around to the beginning:
    IreadIndex = 0;
  }
// calculate the average:
  Iaverage = Itotal / numReadings;
  delay(1);        // delay in between reads for stability

// power reading smoothing

     // subtract the last reading:
  Ptotal = Ptotal - Preadings[IreadIndex];
  // read from the sensor:
  Preadings[PreadIndex] = Pin;
  // add the reading to the total:
  Ptotal = Ptotal + Preadings[PreadIndex];
  // advance to the next position in the array:
  PreadIndex = PreadIndex + 1;
  // if we're at the end of the array...
  if (PreadIndex >= numReadings) {
    // ...wrap around to the beginning:
    PreadIndex = 0;
  }
  // calculate the average:
  Pin = Ptotal / numReadings;
  delay(1);        // delay in between reads for stability

// converting voltage and curret reading to decimal values

  Vin = Vaverage*0.104;
  Iin_raw = (Iaverage-Ioffset)*0.02642*0.25;
  Iin = (2.5247*Iin_raw*Iin_raw)+ (0.9098*Iin_raw) + 0.012;

  Pin = Vin*Iin;
//
//  Vin = analogRead(4);//*0.039;
//  Iin = analogRead(5);//-512)*0.029326;
//  Pin = Vin*Iin;

  x1=otherHandsize*cos(((Vin*9)+135)*0.0175);
  y1=otherHandsize*sin(((Vin*9)+135)*0.0175);
  x2=otherHandsize*cos(((Iin*270)+135)*0.0175);
  y2=otherHandsize*sin(((Iin*270)+135)*0.0175);
  x3=mainHandsize*cos(((Pin*54)+135)*0.0175);
  y3=mainHandsize*sin(((Pin*54)+135)*0.0175);
  
  display.drawLine(VgaugeCenterX, VgaugeCenterY, x1+VgaugeCenterX, y1+VgaugeCenterY, WHITE);
  display.drawCircle(VgaugeCenterX, VgaugeCenterY, otherGaugesize, WHITE);
  for(int angle=135; angle<=405; angle+=45){
     x4=otherGaugesize*cos(angle*0.0175);
     y4=otherGaugesize*sin(angle*0.0175);
     x5=(otherGaugesize-otherTicksize)*cos(angle*0.0175);
     y5=(otherGaugesize-otherTicksize)*sin(angle*0.0175);
     display.drawLine(x4+VgaugeCenterX, y4+VgaugeCenterY, x5+VgaugeCenterX, y5+VgaugeCenterY, WHITE);
  }  
  
  display.drawLine(IgaugeCenterX, IgaugeCenterY, x2+IgaugeCenterX, y2+IgaugeCenterY, WHITE);
  display.drawCircle(IgaugeCenterX, IgaugeCenterY, otherGaugesize, WHITE);
  for(int angle=135; angle<=405; angle+=45){
     x4=otherGaugesize*cos(angle*0.0175);
     y4=otherGaugesize*sin(angle*0.0175);
     x5=(otherGaugesize-otherTicksize)*cos(angle*0.0175);
     y5=(otherGaugesize-otherTicksize)*sin(angle*0.0175);
     display.drawLine(x4+IgaugeCenterX, y4+IgaugeCenterY, x5+IgaugeCenterX, y5+IgaugeCenterY, WHITE);
  }
  
  display.drawLine(PgaugeCenterX, PgaugeCenterY, x3+PgaugeCenterX, y3+PgaugeCenterY, WHITE);
  display.drawCircle(PgaugeCenterX, PgaugeCenterY, mainGaugesize, WHITE);
   for(int angle=135; angle<=405; angle+=45){
     x4=mainGaugesize*cos(angle*0.0175);
     y4=mainGaugesize*sin(angle*0.0175);
     x5=(mainGaugesize-mainTicksize)*cos(angle*0.0175);
     y5=(mainGaugesize-mainTicksize)*sin(angle*0.0175);
     display.drawLine(x4+PgaugeCenterX, y4+PgaugeCenterY, x5+PgaugeCenterX, y5+PgaugeCenterY, WHITE);
  }

  display.setCursor(VgaugeCenterX-13,45);
  display.print("Voltg");
  display.setCursor(VgaugeCenterX-13,55);
  display.print(Vin, 1);
  display.print("V");
  display.setCursor(IgaugeCenterX-13,45);
  display.print("Crrnt");
  display.setCursor(IgaugeCenterX-13,55);
  display.print(Iin);
  display.print("A");
  display.setCursor(PgaugeCenterX-13,45);
  display.print("Power");
  display.setCursor(PgaugeCenterX-13,55);
  display.print(Pin, 1);
  display.print("W");
  
  display.display();
  delay(2);
  display.clearDisplay();
  
  Serial.print("Vin:");
  Serial.print(Vin, 1);
  Serial.print(" Iin:");
  Serial.print(Iaverage);
  Serial.print(" Pin:");
  Serial.print(Pin,1); 
  Serial.print(" Ioffset");
  Serial.print(Ioffset);
  Serial.print("  | ");
  Serial.print(analogRead(voltagePin));
  Serial.print(",");
  Serial.print(analogRead(currentPin));
  Serial.println(pinval);  
}

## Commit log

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2016-08-15 Changing names to allow schematic and board to be linked in eagle
    [MVP.brd, MVP.sch]
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2016-08-15 Replaced .brd file with verson with some components already placed
    [MVP.brd]
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2016-08-17 Issues seen with an offset between arduino current and voltage measurements and expected measurements. Add first pass solution at remedying this offset.
    [MVP_Code.ino]
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2016-08-19 Adding switch and resistors for power measurement mode
    [MVP.brd, MVP.sch]
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2016-08-30 Updating changes to schematics as well as adding BOM .txt file
    [MVP.brd, MVP.sch]
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2016-08-30 adding trace for pin16 on atmega to go to jumper
    [MVP.brd, MVP.sch]
2016-08-30 Change some components connections in schematics and update board layout
    changed top and bottom layer isolation to 0.3
    completed unrouted wires
    rerouted Output to come from capacitor directly
    moved +3V3 near POT2 to allow more space forground trace to penetrate to C1 and C2
    moved decoupling caps C4 and C1 closer to IC1 and IC3, respectively
    added several ground stitching vias between top and bottom layer
    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
    [MVP.brd, MVP.sch]
2016-08-30 moved VOUT+, USB_OUT, VIN_BUCK/BOOST and VIN_BUCK closer to the edges as these will most likely be replaced with screw terminals (I couldn't find the component for these in eagle)
    [MVP.brd]
2016-09-07 Changed position of 5V and overvoltage on JP2
    [MVP.brd, MVP.sch]
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2016-09-12 Updated circuit to reflect change from ACS711 to ACS712
    [MVP.brd, MVP.sch]
2016-09-12 Changing name of IC1 to reflect change of current sensing module
    [MVP.brd, MVP.sch]
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2016-09-13 making board more compact and replacing pots with 3296W as these are easier to find
    [MVP.brd, MVP.sch]
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2016-09-13 changing component names so the make sense again
    [MVP.brd, MVP.sch]
2016-09-13 replacing switch on PCB with pin header as originally intended
    [MVP.brd, MVP.sch]
2016-09-13 changing all caps and resistors to correct size
    [MVP.brd, MVP.sch]
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2016-09-14 flipping Q1 and Q2 back to top to save space. This is due to them never getting hot during testing so there did not seem to be a good reason for them to be on the bottom
    [MVP.brd]
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2016-09-14 changed all pin headers from 7.62mm pitch to 5.08mm pitch
    [MVP.brd, MVP.sch]
2016-09-14 resolved clearnace issues and sorted a connection issue between pot3 and Q1
    [MVP.brd, MVP.sch]
2016-09-14 moved C2 into a more central position away from VOUT+ header
    [MVP.brd]
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2016-09-14 corrected names and values of components
    [MVP.brd, MVP.sch]
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2016-09-18 changin hole layout so that all mounting holes are he same distance from the edges
    [MVP.brd]
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2016-09-18 Rerouting PCB to fit the enclosure being ordered. Holes placed so that they will fit over enclosure holes
    [MVP.brd]
2016-09-18 Removed dimensions and cleared remaining DRC errors (mainly overlap from stray vias
    [MVP.brd]
2016-09-19 widening board to accomodate pin header on left hand side
    [MVP.brd]
2016-09-19 moved VIN+ and VIN- to allow more space between components
    [MVP.brd]
2016-09-20 Adding gerbers and PDF files of schematics and new file folder structure
    [LED_board.brd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]
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2016-10-11 updating folder structure and improving naming in MVP board
    [LED_board.brd, LED_board.sch, MVP.brd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]
2016-10-11 changed that name of header to LED_CONTROL_IN / OUT
    [LED_board.brd, LED_board.sch, MVP.brd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]
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2016-11-02 correcting cap values on atmega crystal
    [Main_board.brd, Main_board.sch]
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2016-11-23 added overvoltage protection, replaced fuse holder footprint, stopped irfs from overlapping with ground stitching vias, moved dummy load resistors and corrected pin header pitch
    [Main_board.brd, Main_board.sch]
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2016-11-28 fixing minor drc errors and repostionings monting holes
    [Main_board.brd, Main_board.sch]
2016-11-28 fixing another minor drc
    [Main_board.brd]
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2016-11-28 another flicking drc error
    [Main_board.brd]
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2017-02-13 removing dummy load and adding in lm2596 boards to PCB
    [Main_board.brd, Main_board.sch]
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2017-03-03 minor changes to USB board and updating gerbers
    [LED_board.GBL, LED_board.GBS, LED_board.GTL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]
2017-03-09 adding updated gerbers and moving name of arduino DIO
    [Main_board.brd]
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2017-04-13 adding new current sensor and buck converter for USB power supply
    [Main_board.brd, Main_board.sch]
2017-04-14 adding new arduino voltage reg and improved schematic symbol for CS30
    [Main_board.brd, Main_board.sch]
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2017-04-14 Minor changes (no idea what it is but it should be minor)
    [Main_board.sch]
2017-04-15 addig smoothing caps for LM317 out and CS80 inputs
    [Main_board.brd, Main_board.sch]
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2017-04-25 adding ground to AIO and general tidy up
    [Main_board.brd, Main_board.sch]
2017-06-10 Moving fuse close to output rather than input
    [Main_board.brd, Main_board.sch]
2017-06-11 adding 5.1v zeners and LEDs to outputs of voltage regulators
    [Main_board.brd, Main_board.sch]
2017-06-11 Adding new overvoltage protection FETs and renaming nets
    [Main_board.brd, Main_board.sch]
2017-06-11 Moving everything into postion and adding fuse to start of circuit
    [Main_board.brd, Main_board.sch]
2017-06-11 moving everything into place and DRC check complete
    [Main_board.brd, Main_board.sch]
2017-06-13 Moving buck converter and re-arranging other components as needed
    [Main_board.brd, Main_board.sch]
2017-06-14 Tidying up ground planes and traces. Adding ground stitching vias
    [Main_board.brd, Main_board.sch]
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2017-06-26 moving res divider for vin measurement to bottom of PCB
    [Main_board.brd]
2017-06-26 moving input terminal closer to edge of pcb
    [Main_board.brd]
2017-06-26 mocing component names to be in better places (not overlapping pads)
    [Main_board.brd]
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2017-09-03 replaced SMD resistors, caps and MOSFETs with TH components
    [Main_board.brd, Main_board.sch]
2017-09-04 correcting mosfet postion
    [Main_board.brd, Main_board.sch]
2017-09-18 renamed files to reflect two versions of L.E.One and replacing ATmega 328 with arduino nano
    [Main_board_SMD.brd, Main_board_SMD.sch, Main_board_TH.brd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]
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2017-10-15 Removed: pin headers for arduino, button for arduino and LED for LM2596. Inital board layout complete. Sub modules pretty much done but overall layout still needs work
    [Main_board_TH.brd, Main_board_TH.sch]
2017-10-15 high level layout complete and adding in BOM
    [Main_board_TH.brd, Main_board_TH.sch]
2017-10-16 completing passive protection and active protection alignment and renaming components sequentially (i.e. R1, R2, R3, ...)
    [Main_board_TH.brd, Main_board_TH.sch]
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2017-10-17 Redoing names of sections so that they fit and adding in versioning and a place for people to put their names
    [Main_board_TH.brd, Main_board_TH.sch]
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

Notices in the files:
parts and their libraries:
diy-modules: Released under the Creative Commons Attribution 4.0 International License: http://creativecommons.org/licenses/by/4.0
